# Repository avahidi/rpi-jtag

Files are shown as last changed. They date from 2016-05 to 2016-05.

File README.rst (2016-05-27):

========
RPi-JTAG
========

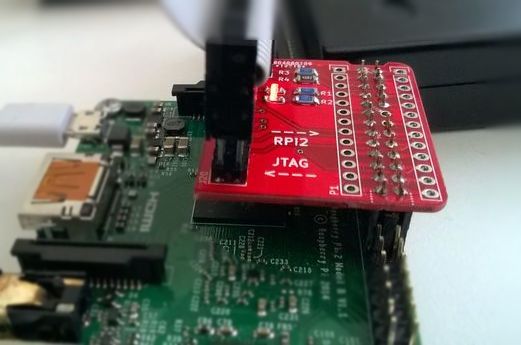
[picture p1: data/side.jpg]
version 0.1 in action


Raspberry Pi IO header to JTAG IDC-20P connector, plus optional UART connectors and power indicators.

Note that JTAG pins are shared with GPIO, which you will need to re-configure in order to enable JTAG.
I use my minipi_ bootloader to do this, which gives me access to JTAG early in the boot.
But you can also do this manually from the u-boot prompt::

    mw.l 0x3F200000 0x00002000
    mw.l 0x3F200008 0x0061B0C0

license
-------

CERN OHL v1.2, because lets face it, this is rocket science ;)

see LICENSE_ for details

download
--------

The repository contains the KiCad project. There are also standalone schematics_ and gerber files for
oshpark_ and dirtypcbs_ (and itead/seeed). Note that I have only tested dirtypcbs.

.. _minipi: https://bitbucket.org/vahidi/mini-pi-bootloader
.. _oshpark: https://bitbucket.org/vahidi/rpi-jtag/raw/master/data/oshpark.zip
.. _dirtypcbs: https://bitbucket.org/vahidi/rpi-jtag/raw/master/data/dirtypcbs.zip
.. _schematics: https://bitbucket.org/vahidi/rpi-jtag/raw/master/data/schema.pdf
.. _LICENSE: https://bitbucket.org/vahidi/rpi-jtag/raw/master/LICENSE

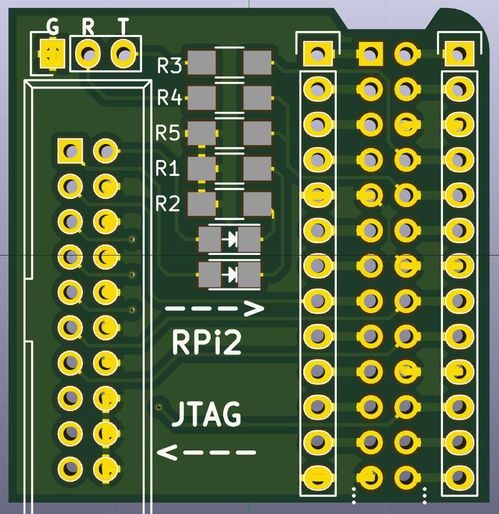
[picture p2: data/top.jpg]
top view


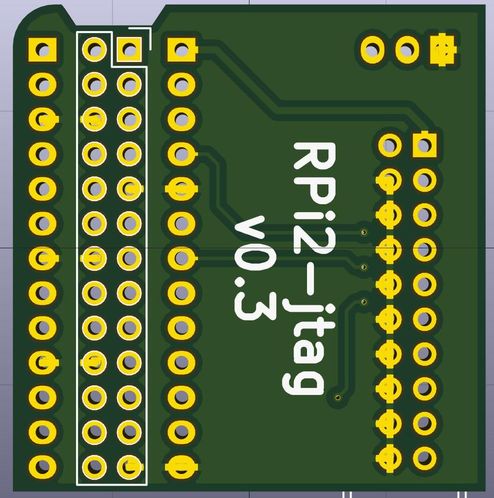
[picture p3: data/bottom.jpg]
botom view


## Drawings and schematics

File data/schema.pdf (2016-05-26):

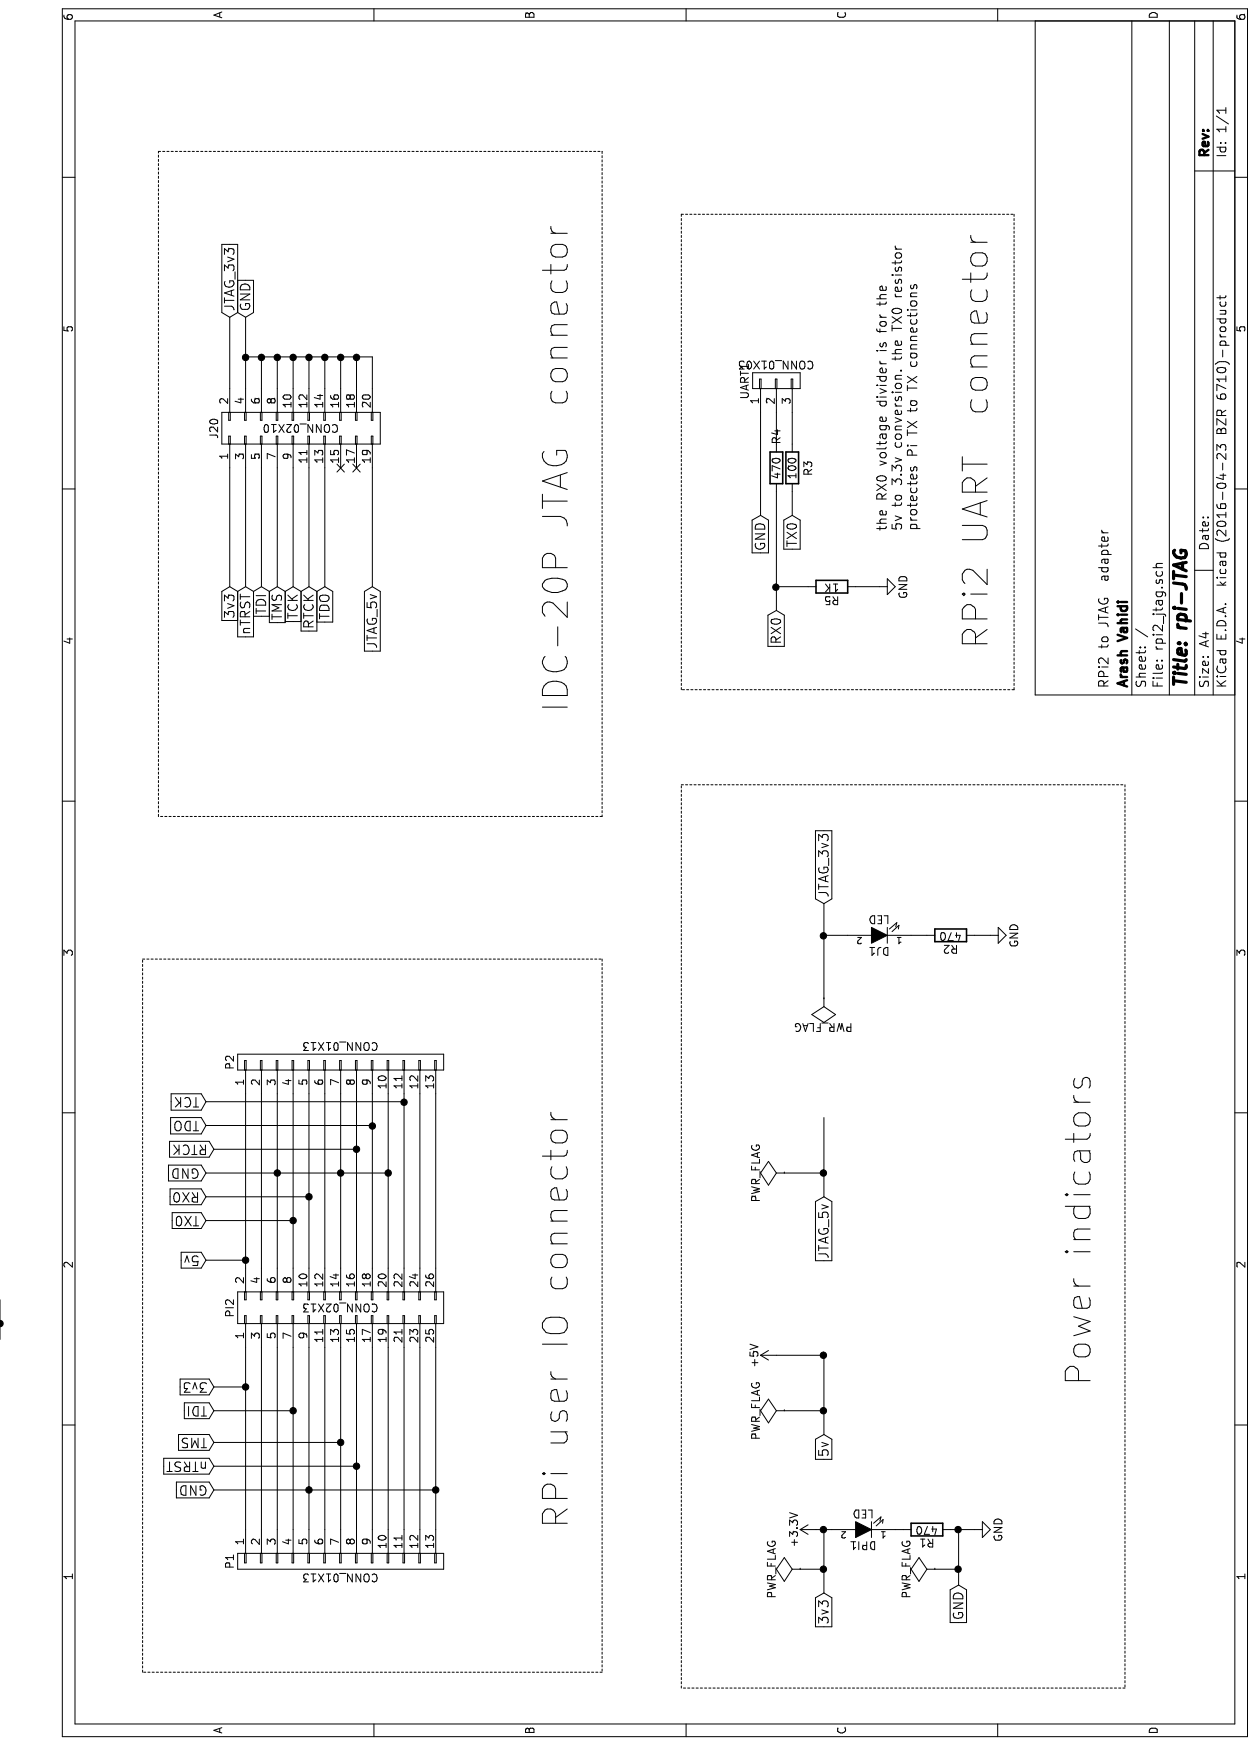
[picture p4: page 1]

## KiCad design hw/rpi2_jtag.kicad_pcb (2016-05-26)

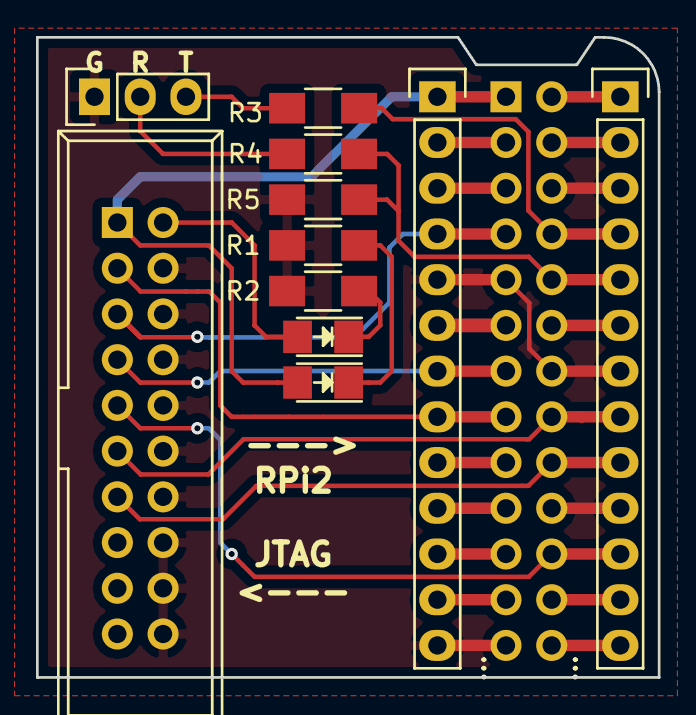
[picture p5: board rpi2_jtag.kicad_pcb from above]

Board: 2 copper layers, 34.5 x 35.6 mm, 12 parts (1 on the bottom side), 27 nets.

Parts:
DJ1: LED; LED_1206
DPI1: LED; LED_1206
J20: CONN_02X10; IDC_Header_Straight_20pins
P1, P2: CONN_01X13; Pin_Header_Straight_1x13
PI2: CONN_02X13; Socket_Strip_Straight_2x13
R1, R2, R4: 470; R_1206_HandSoldering
R3: 100; R_1206_HandSoldering
R5: 1K; R_1206_HandSoldering
UART1: CONN_01X03; Pin_Header_Straight_1x03

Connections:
3v3: DPI1.2, J20.1, P1.1, PI2.1
5v: P2.1, PI2.2
GND: J20.4, J20.6, J20.8, J20.10, J20.12, J20.14, J20.16, J20.18, J20.20, P1.5, P1.13, P2.3, P2.7, P2.10, PI2.6, PI2.9, PI2.14, PI2.20, PI2.25, R1.1, R2.1, R5.1, UART1.1
JTAG_3v3: DJ1.2, J20.2
unnamed: DJ1.1, R2.2
unnamed: DPI1.1, R1.2
unnamed: P1.2, PI2.3
unnamed: P1.3, PI2.5
unnamed: P1.6, PI2.11
unnamed: P1.9, PI2.17
unnamed: P1.10, PI2.19
unnamed: P1.11, PI2.21
unnamed: P1.12, PI2.23
unnamed: P2.2, PI2.4
unnamed: P2.6, PI2.12
unnamed: P2.12, PI2.24
unnamed: P2.13, PI2.26
unnamed: R3.1, UART1.3
unnamed: R4.1, UART1.2
RTCK: J20.11, P2.8, PI2.16
RX0: P2.5, PI2.10, R4.2, R5.2
TCK: J20.9, P2.11, PI2.22
TDI: J20.5, P1.4, PI2.7
TDO: J20.13, P2.9, PI2.18
TMS: J20.7, P1.7, PI2.13
TX0: P2.4, PI2.8, R3.2
nTRST: J20.3, P1.8, PI2.15

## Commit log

2016-05-05 v0.2 imported from private repo
    [rpi2_jtag.kicad_pcb, rpi2_jtag.sch]
2016-05-26 v0.3: corrected RX/TX pins, added voltage divider to RX. changed JTAG connector to IDC-20 v0.x: added License and fixed missing grebers. updated README with links
    [rpi2_jtag.kicad_pcb, rpi2_jtag.sch]
